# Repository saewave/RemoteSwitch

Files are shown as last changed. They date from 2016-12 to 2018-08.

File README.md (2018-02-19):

# RemoteSwitch

Проект RemoteSwitch создан для тех, кто самостоятельно занимается разработкой систем домайшеней автоматизации но сталкивается с рядом проблем, таких как:
- передача данных по радио каналу;
- разработка схемотехники для исполнительных устройств;
- разработка модуля для управления устройствами (хаб);
- организации беспроводной сети.

Проект домашней автоматизации на базе SaeWave RemoteSwitch решает полностью или частично все вышеперечисленные проблемы. На данный момент характеристики системы такие:
- Частота радиоканала 433 МГц.
- Скорость передачи данных от 1200 кБит
- Дальность устойчивого приема на открытом пространстве - 300м (дальность зависит от помех, наличия препятствий и используемых антенн).
- Подтверждение приема - да (при соответствующих настройках)
- Повторение отправки пакета - да (при соответствующих настройках)
- Подпись пакета - CRC
- Возможность обновления прошивки по воздуху

Проект является полностью открытыми, все исходные коды, схемы и списки деталей являются общедоступными для использования и повторения.

Проект распространяется под лицензией GPLv3 - это означает то, что если ваш проект будет полностью или частично построен на базе SaeWave RemoteSwitch он должен быть открытым.

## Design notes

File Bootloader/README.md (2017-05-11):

Шаблон для бутлоадера под STM32F0xx серию. Бутлоадер позволяет выполнить произвольный код, а потом перейти на произвольный адрес дя выполнения основного кода программы. Для этого программа должна быть загружена во флеш память и адрес, на который будет передано управление должен содержать начало исполняемого кода.
Для корректной работы прерываний основной программы таблица векторов должна быть перенесена в начало оперативной памяти и смещана относительно размера бутлоадера. Это особенности архитектуры STM32F0 серии. В других сериях мы можем переопределить саму таблицу векторов без ее полного переноса.

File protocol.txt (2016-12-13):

HUB Package structure (request)
	header: 1
	hubID:  5 (the length maybe configured in header) (should be same as device address for nRF24L01)
	command:1 (the length maybe configured in header)
	data:   depends on command

header bits (MSB-LSB):
	reserved
	reserved
	reserved
	reserved
	reserved
	number of package: 0=first package, 1=second (in this case data should be concatenated to data received early)
	hubID length: 0=5 byte, 1=8 byte
	command length: 0=1 byte, 2=more than 1 byte

Device package structure (request/response)
	header: 1
	deviceID: 5 (should be same as device address for nRF24L01)

Формирование адреса устройства:
Адрес устройства состоит из 5 байт.
При включении устройства, не важно, хаб это или исполнительное устройство адрес формируется их последних 5 байт серийного номера МК.
Если получить адрес МК не представляется возможным, то адрес устройства = 00-00-00-00-00 (или тот, который задан в файле nRF24L01P)
	
Поиск нового устройства хабом:
0) Подключение устройства к питанию, инициализация устройства. Включение приема или передачи данных.
1) На устройстве должен быть включен режим обнаружения. При этом устройство переходит в режим приема с адресом 00-00-00-00-00
2) Хаб отправляет команду обнаружения на адрес 00-00-00-00-00. Команда содержить автоматически (или тот, который задан в файле nRF24L01P) сгенерированный уникальный адрес для конкретного устройста.
3) Устройство принимает команду и распознает её. 
4) Формирует и отправляет ответ, данные ответа содержат команду подтверждения обнаружения, реальный (присвоенный) адрес устройства и тип устройства. Так же может содержать доп. информацию в зависимости от типа.
   4.1) Устройство переходит в штатный режим работы. При этом, если требуется режим приема, то устанавливается реальный адрес устройства полученный от хаба.
   4.2) Устройство так же запоминает адрес хаба у себя в памяти.
5) Хаб получает ответ от устройства, производит поиск устройств среди ранее сохраненных в памяти и обновляет данные либо добавляет новое устройство.

Примечание:
	Для работы в штатном режиме каждая полученная команда сравнивается с адресом хаба к которому была произведена привязка и только потом передается на исполнение.
	Это необходимо для того, чтоб не было ложных срабатываний от других хабов. Устройство можно подвязать к нескольким хабам (в этом случае алгоритм привязки меняется)
	
Передача данных от хаба к устройству:
0) Хаб, получив команду на передачу данных на устройство производит поиск устройства в таблице привязанных устройств и, если таковое устройство было ранее добавлено, вызывает функцию формирования пакета.
1) Пакет для передачи формируется из заголовка, данных и подписи.
2) Сформированный пакет передается на передатчик для отправки устройству. При этом сам процесс передачи контроллируется передатчиком.
3) Хаб отслеживает состояние отправки данных по внешнему прерыванию от передатчика, а так же по состоянию статусного регистра передатчика.
4) В зависимости от того, были ли переданны данные или нет, хаб возвращает статусную информацию в USART.

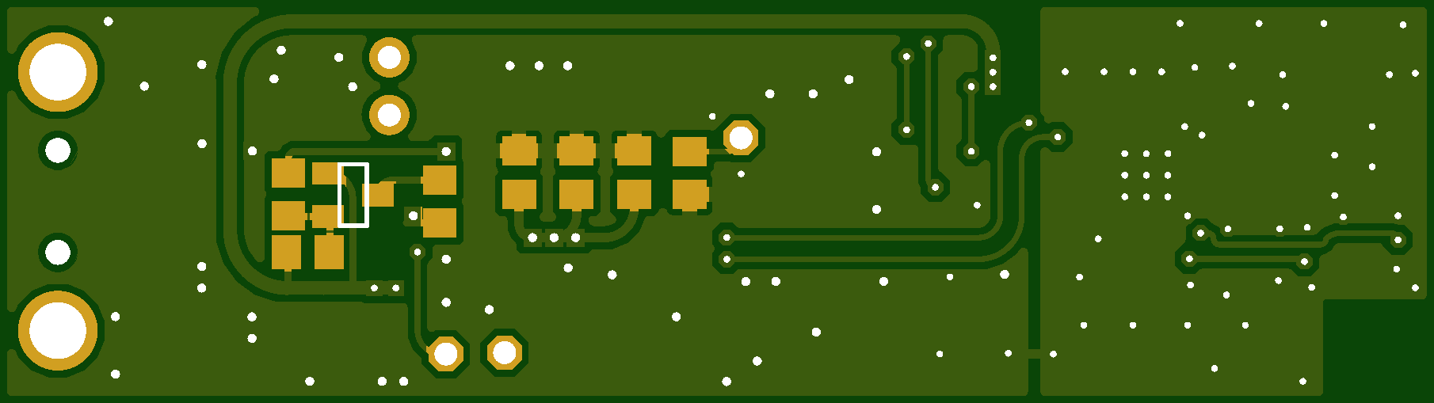
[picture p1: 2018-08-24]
SchematicAndBoards/Hub USB 2.0/Hub USB 2.0 Bottom.png

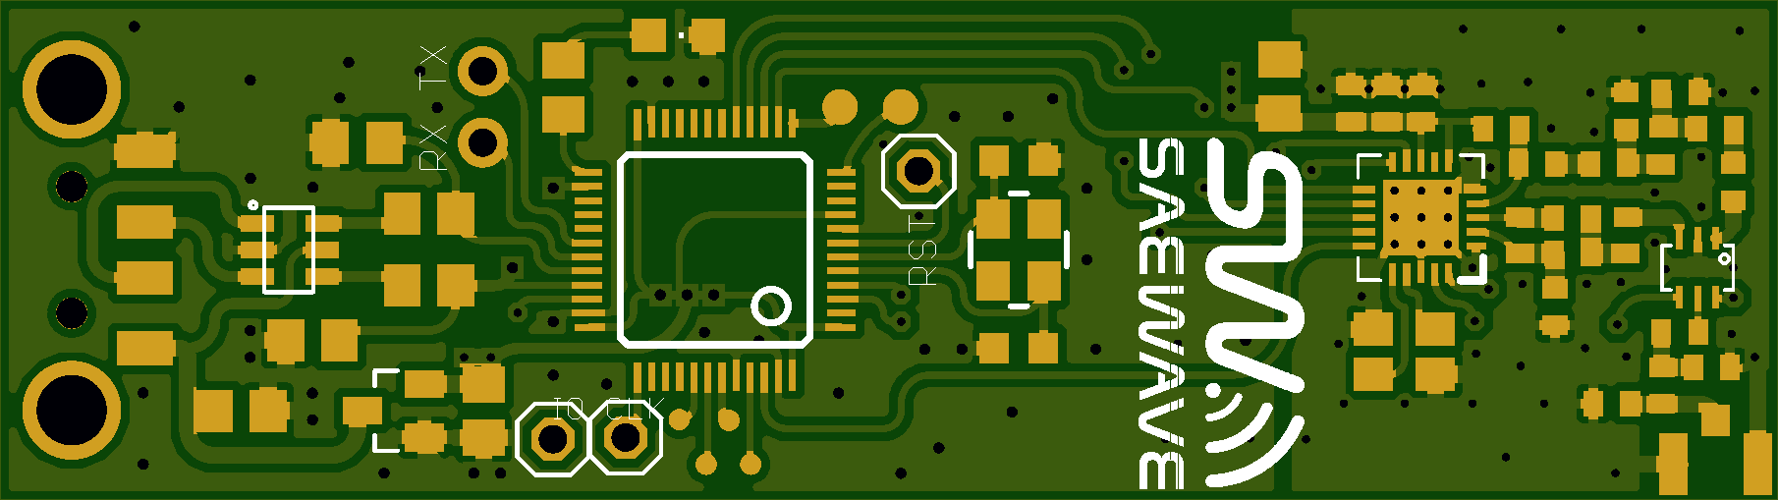
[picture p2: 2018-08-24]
SchematicAndBoards/Hub USB 2.0/Hub USB 2.0 Top.png

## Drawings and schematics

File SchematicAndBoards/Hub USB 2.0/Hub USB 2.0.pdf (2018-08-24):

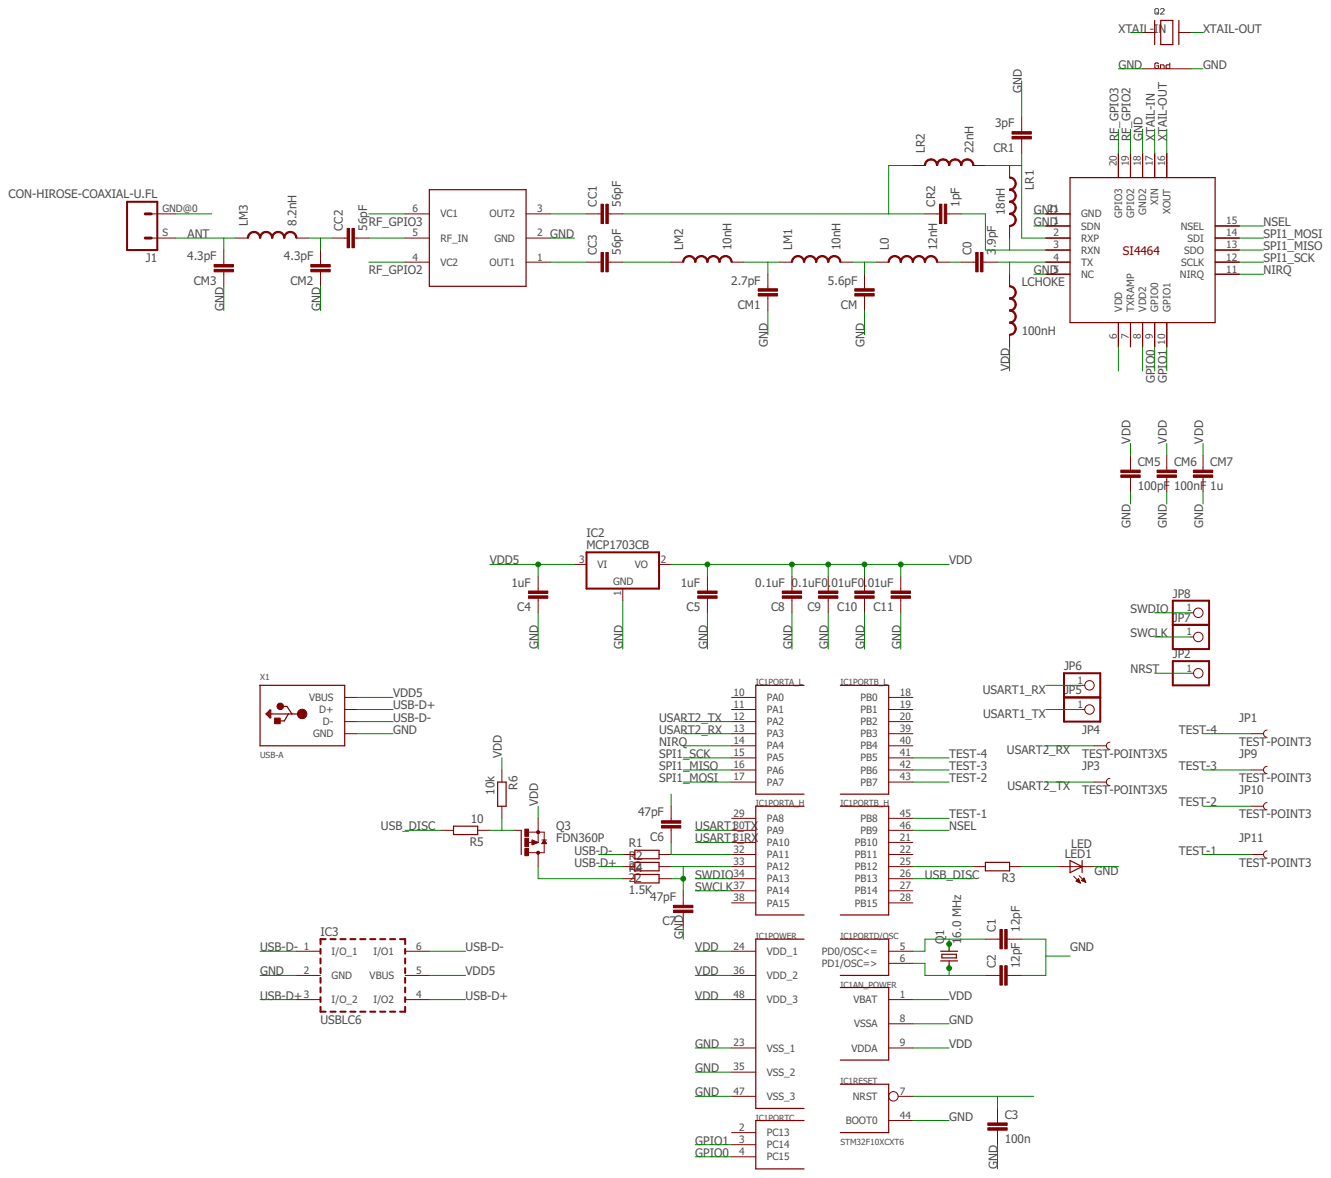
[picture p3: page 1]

CON-HIROSE-COAXIAL-U.FL

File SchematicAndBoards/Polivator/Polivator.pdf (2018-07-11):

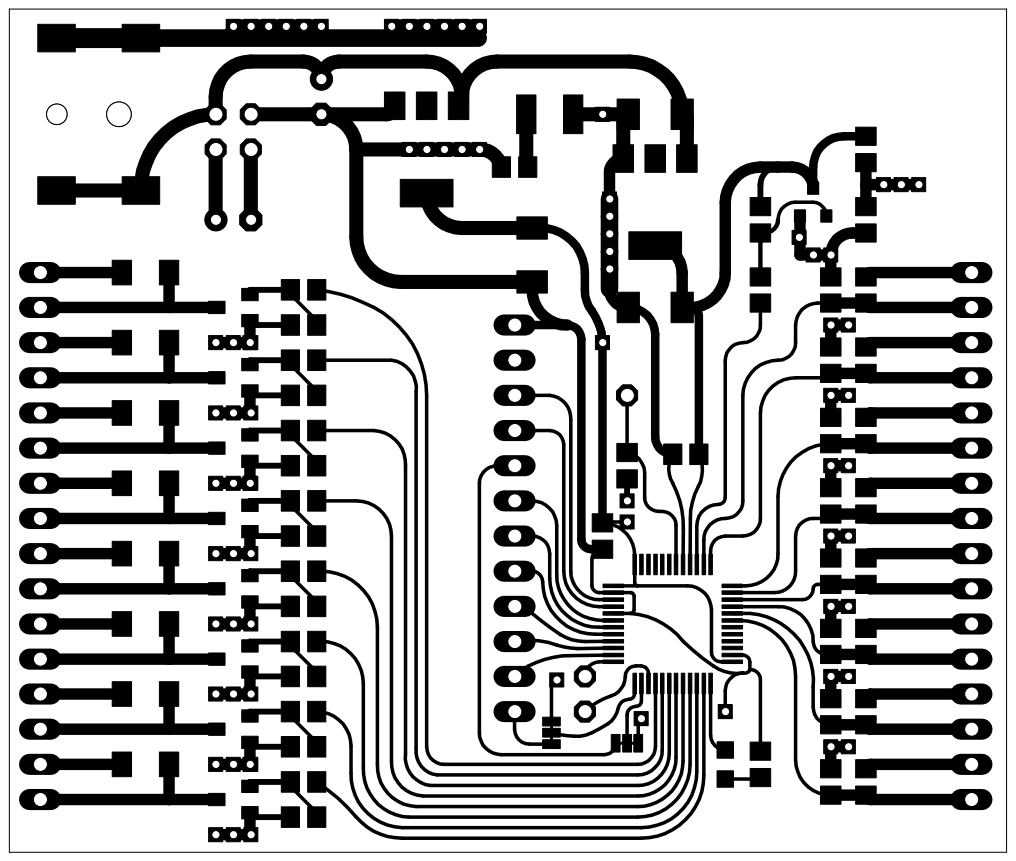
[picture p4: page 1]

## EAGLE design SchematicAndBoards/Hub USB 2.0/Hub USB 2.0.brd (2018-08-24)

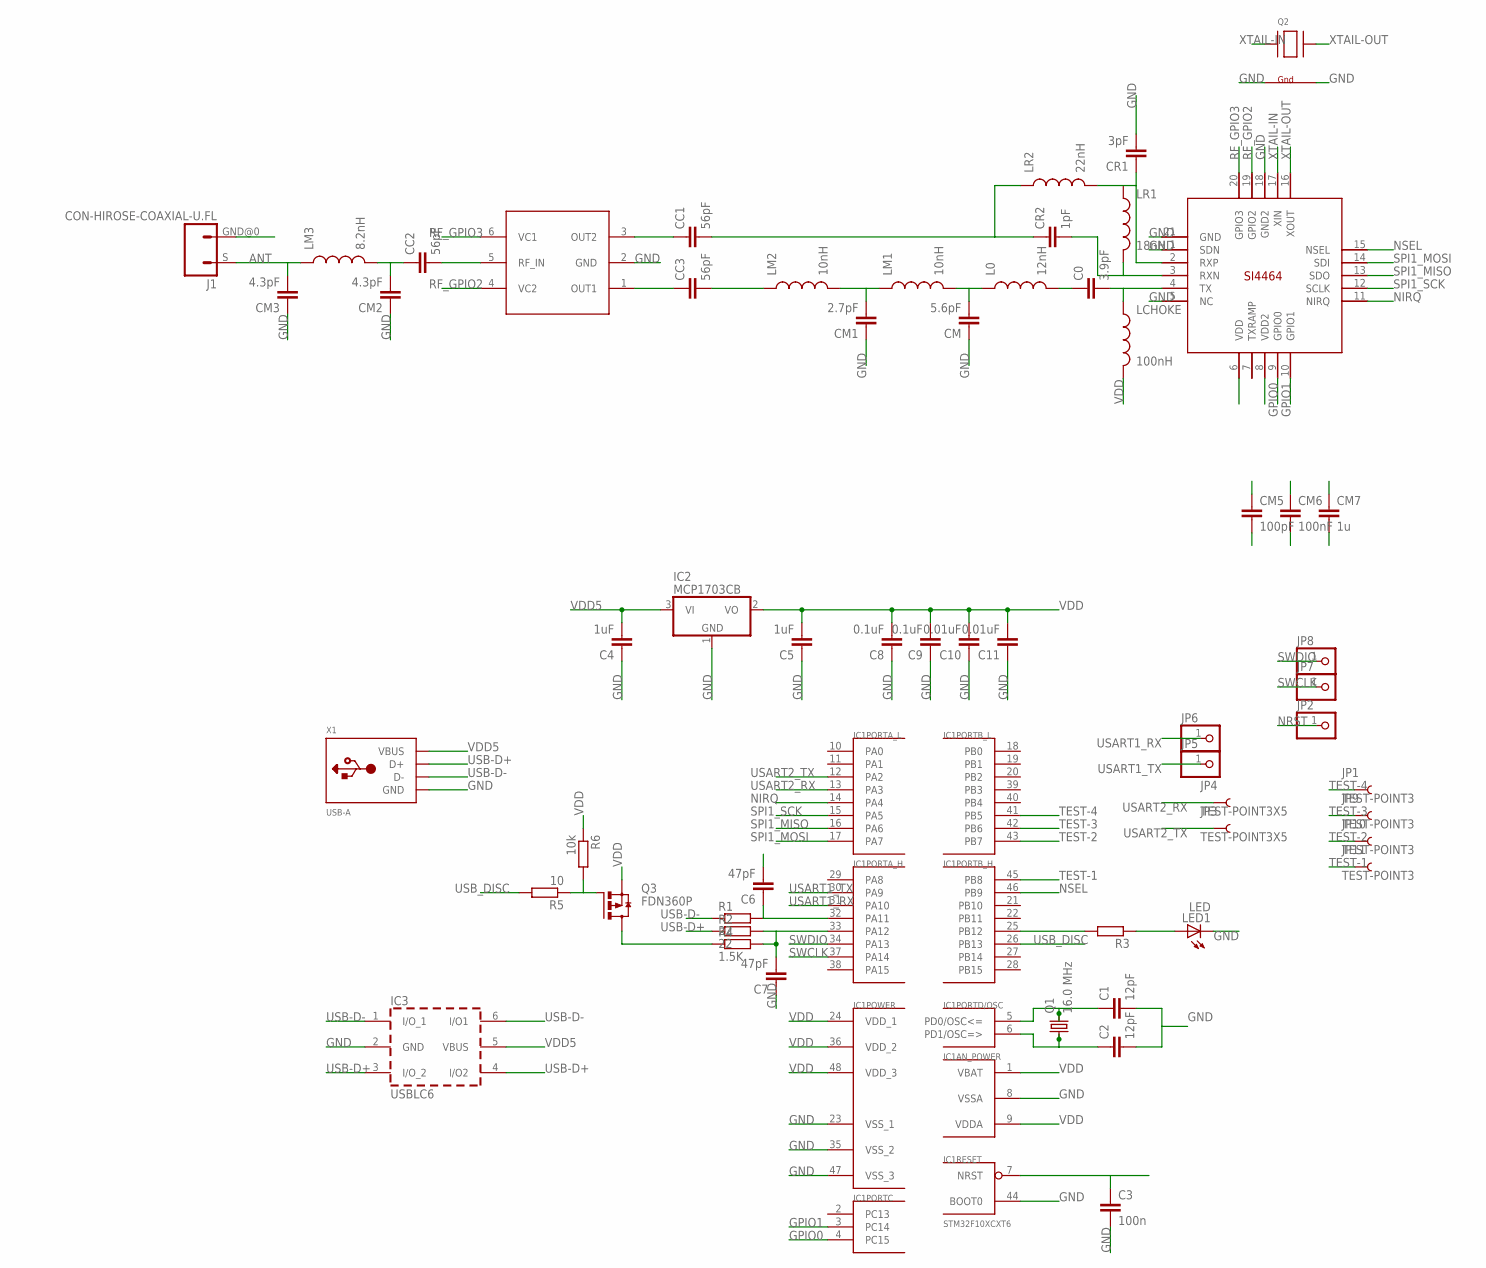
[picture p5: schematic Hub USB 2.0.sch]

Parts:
C0: 3.9pF; C0402
C1, C2: 12pF; C0603K
C3: 100n; C0805
C4, C5: 1uF; C0805
C6, C7: 47pF; C0805
C8, C9: 0.1uF; C0805
C10, C11: 0.01uF; C0805
CC1, CC2, CC3: 56pF; C0402
CM: 5.6pF; C0402
CM1: 2.7pF; C0402
CM2, CM3: 4.3pF; C0402
CM5: 100pF; C0402
CM6: 100nF; C0402
CM7: 1u; C0402
CR1: 3pF; C0402
CR2: 1pF; C0402
IC1: STM32F10XCXT6; TQFP48
IC2: MCP1703CB; SOT23
IC3: USBLC6; SOT-23-6L
J1: CON-HIROSE-COAXIAL-U.FL; CON-U.FL
JP1, JP9, JP10, JP11: TEST-POINT3; PAD.03X.03
JP2, JP7, JP8: PINHD-1X1; 1X01
JP3, JP4: TEST-POINT3X5; PAD.03X.05
JP5, JP6: PINHD-1X1CB; 1X01-CLEANBIG
L0: 12nH; C0402
LCHOKE: 100nH; C0402
LED1: LED; CHIPLED_0805
LM1, LM2: 10nH; C0402
LM3: 8.2nH; C0402
LR1: 18nH; C0402
LR2: 22nH; C0402
Q1: 16.0 MHz; CRYSTAL-SMD-3.2X2.5
Q2: XTAL-4-3225; NX3225
Q3: FDN360P; SUPER-SOT3
R1, R2: 22; R0805
R3: R-EU_R0805; R0805
R4: 1.5K; R0805
R5: 10; R0805
R6: 10k; R0805
U$1: SI4464; QFN20+GNDPAD
U$2: UPG2179TB; SUPER_MINIMOLD
X1: USB-A; MOLEX_480371000

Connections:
ANT: CM3.2, J1.S (1), LM3.1
GND: C1.2, C2.2, C3.2, C4.1, C5.1, C6.2, C7.1, C8.1, C9.1, C10.1, C11.1, CM.1, CM1.1, CM2.1, CM3.1, CM5.2, CM6.2, CM7.2, CR1.2, IC1.8 (VSSA), IC1.23 (VSS_1), IC1.35 (VSS_2), IC1.44 (BOOT0), IC1.47 (VSS_3), IC2.1 (GND), IC3.2 (GND), J1.GND@0 (2), LED1.C, Q2.2 (G2), Q2.4 (G1), U$1.1 (SDN), U$1.5 (NC), U$1.18 (GND2), U$1.21 (GND), U$2.2 (GND), X1.4 (GND)
GPIO0: IC1.4 (PC15), U$1.9 (GPIO0)
GPIO1: IC1.3 (PC14), U$1.10 (GPIO1)
unnamed: C1.1, IC1.5 (PD0/OSC<=), Q1.3 (2)
unnamed: C2.1, IC1.6 (PD1/OSC=>), Q1.1
unnamed: C0.2, LCHOKE.1, U$1.4 (TX)
unnamed: LED1.A, R3.1
unnamed: C0.1, L0.2
unnamed: C7.2, IC1.33 (PA12), R2.2, R4.2
unnamed: CM.2, L0.1, LM1.2
unnamed: CM1.2, LM1.1, LM2.2
unnamed: CC2.1, CM2.2, LM3.2
unnamed: C6.1, IC1.32 (PA11), R1.2
unnamed: CC3.1, U$2.1 (OUT1)
unnamed: CR2.2, LR1.2, U$1.3 (RXN)
unnamed: CC1.1, U$2.3 (OUT2)
unnamed: CR1.1, LR1.1, LR2.2, U$1.2 (RXP)
unnamed: IC1.25 (PB12), R3.2
unnamed: CC2.2, U$2.5 (RF_IN)
unnamed: CC3.2, LM2.1
unnamed: CC1.2, CR2.1, LR2.1
unnamed: Q3.3 (D), R4.1
unnamed: Q3.1 (G), R5.1, R6.2
NIRQ: IC1.14 (PA4), U$1.11 (NIRQ)
NRST: C3.1, IC1.7 (NRST), JP2.1
NSEL: IC1.46 (PB9), U$1.15 (NSEL)
RF_GPIO2: U$1.19 (GPIO2), U$2.4 (VC2)
RF_GPIO3: U$1.20 (GPIO3), U$2.6 (VC1)
SPI1_MISO: IC1.16 (PA6), U$1.13 (SDO)
SPI1_MOSI: IC1.17 (PA7), U$1.14 (SDI)
SPI1_SCK: IC1.15 (PA5), U$1.12 (SCLK)
SWCLK: IC1.37 (PA14), JP7.1
SWDIO: IC1.34 (PA13), JP8.1
TEST-1: IC1.45 (PB8), JP11.P$1
TEST-2: IC1.43 (PB7), JP10.P$1
TEST-3: IC1.42 (PB6), JP9.P$1
TEST-4: IC1.41 (PB5), JP1.P$1
USART1_RX: IC1.31 (PA10), JP6.1
USART1_TX: IC1.30 (PA9), JP5.1
USART2_RX: IC1.13 (PA3), JP4.P$1
USART2_TX: IC1.12 (PA2), JP3.P$1
USB-D+: IC3.3 (I/O_2), IC3.4 (I/O2), R2.1, X1.3 (D+)
USB-D-: IC3.1 (I/O_1), IC3.6 (I/O1), R1.1, X1.2 (D-)
USB_DISC: IC1.26 (PB13), R5.2
VDD: C5.2, C8.2, C9.2, C10.2, C11.2, CM5.1, CM6.1, CM7.1, IC1.1 (VBAT), IC1.9 (VDDA), IC1.24 (VDD_1), IC1.36 (VDD_2), IC1.48 (VDD_3), IC2.2 (VO), LCHOKE.2, Q3.2 (S), R6.1, U$1.6 (VDD), U$1.8 (VDD2)
VDD5: C4.2, IC2.3 (VI), IC3.5 (VBUS), X1.1 (VBUS)
XTAIL-IN: Q2.1 (X1), U$1.17 (XIN)
XTAIL-OUT: Q2.3 (X2), U$1.16 (XOUT)

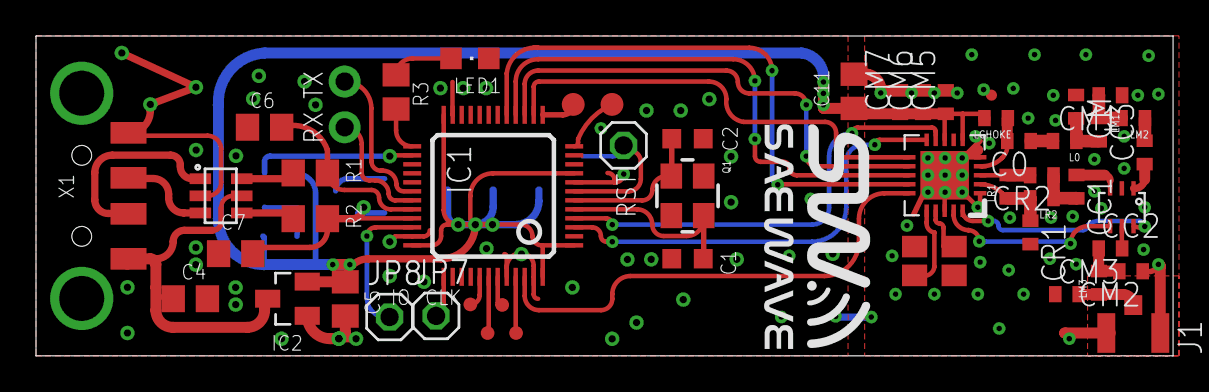
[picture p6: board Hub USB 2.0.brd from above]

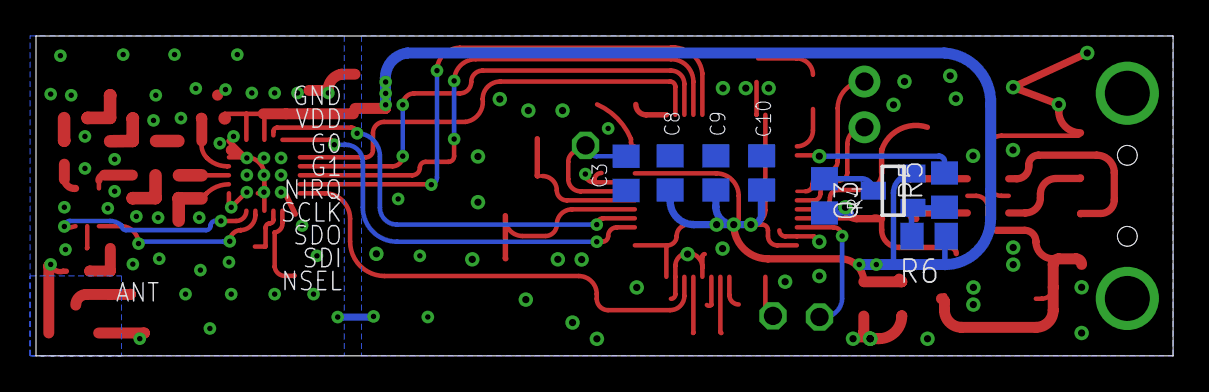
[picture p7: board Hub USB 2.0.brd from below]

Board: 2 copper layers, 63.2 x 17.8 mm, 59 parts (8 on the bottom side), 49 nets.

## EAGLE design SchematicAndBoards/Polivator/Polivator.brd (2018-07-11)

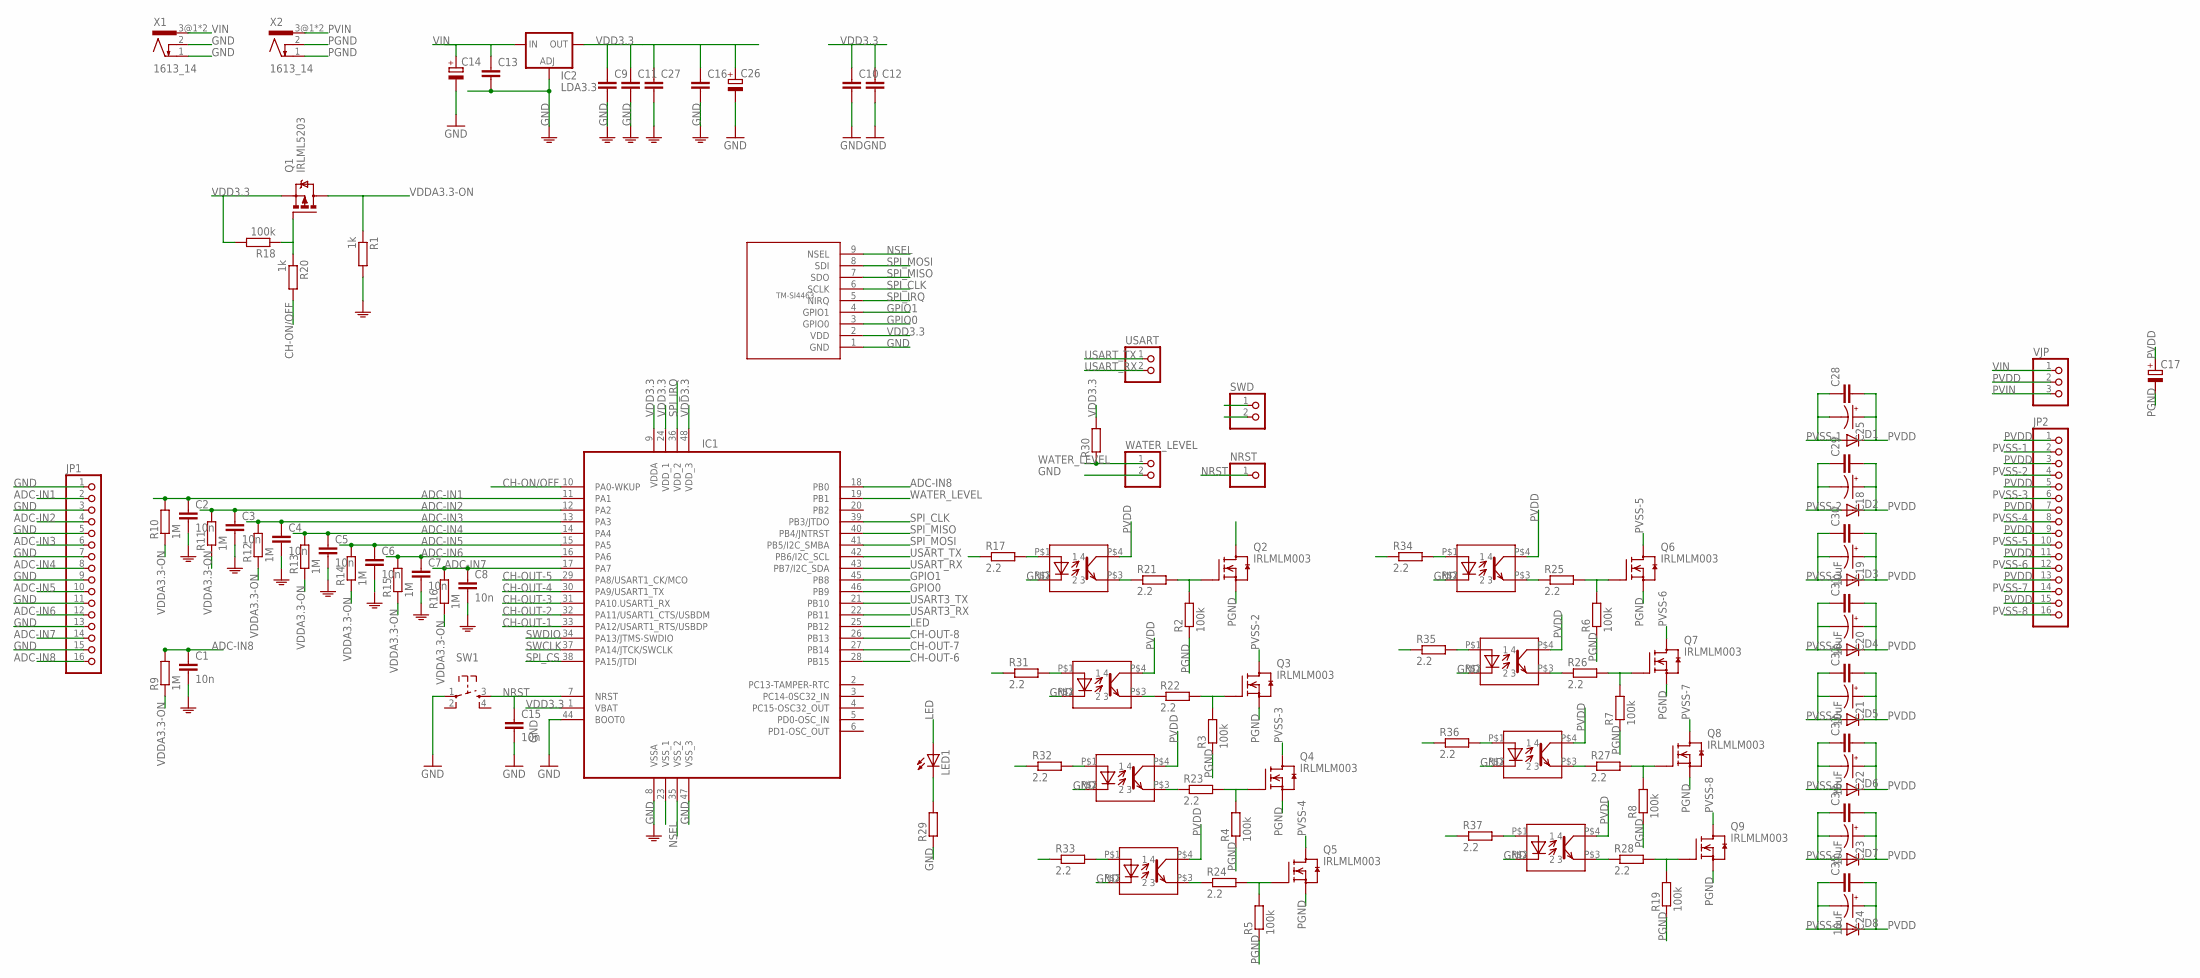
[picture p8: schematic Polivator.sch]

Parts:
C1, C2, C3, C4, C5, C6, C7, C8, C15: 10n; C0805
C9, C10: C-EUC3216; C3216
C11, C12, C16, C27, C28, C29, C30, C31, C32, C33, C34, C35: C-EUC0805; C0805
C13: C-EUC1808; C1808
C14, C26: CPOL-EUE2.5-5; E2,5-5
C17: CPOL-EUE2.5-6; E2,5-6
C18, C25: CAP_POL1206; EIA3216
C19, C20, C21, C22, C23, C24: 10uF; EIA3216
D1, D2, D3, D4, D5, D6, D7, D8: DIODE-SOD80C; SOD80C
IC1: IC_UC_STM32; LQFP48
IC2: LDA3.3; SOT223
JP1, JP2: PINHD-1X16; 1X16
LED1: LEDCHIPLED_0805; CHIPLED_0805
NRST: PINHD-1X1; 1X01
Q1: IRLML5203; MICRO3
Q2, Q3, Q4, Q5, Q6, Q7, Q8, Q9: IRLMLM003; SOT23
R1, R20: 1k; R0805
R2, R3, R4, R5, R6, R7, R8, R18, R19: 100k; R0805
R9, R10, R11, R12, R13, R14, R15, R16: 1M; R0805
R17, R21, R22, R23, R24, R25, R26, R27, R28, R31, R32, R33, R34, R35, R36, R37: 2.2; R0805
R29, R30: R-EU_R0805; R0805
SW1: SW_TACT_4P; SW_TACT_SMALL
SWD: PINHD-1X2; 1X02
U$8: TM-SI4463; TM-SI4463-SMD
U$10, U$11, U$13, U$16, U$18, U$20, U$23, U$24: PC817-SMD
USART: PINHD-1X2; 1X02
VJP: PINHD-1X3; 1X03
WATER_LEVEL: PINHD-1X2; 1X02
X1, X2: 1613_14

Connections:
ADC-IN1: C2.1, IC1.11 (PA1), JP1.2, R10.2
ADC-IN2: C3.1, IC1.12 (PA2), JP1.4, R11.2
ADC-IN3: C4.1, IC1.13 (PA3), JP1.6, R12.2
ADC-IN4: C5.1, IC1.14 (PA4), JP1.8, R13.2
ADC-IN5: C6.1, IC1.15 (PA5), JP1.10, R14.2
ADC-IN6: C7.1, IC1.16 (PA6), JP1.12, R15.2
ADC-IN7: C8.1, IC1.17 (PA7), JP1.14, R16.2
ADC-IN8: C1.1, IC1.18 (PB0), JP1.16, R9.2
CH-ON/OFF: IC1.10 (PA0-WKUP), R20.2
CH-OUT-1: IC1.33 (PA12/USART1_RTS/USBDP), R17.1
CH-OUT-2: IC1.32 (PA11/USART1_CTS/USBDM), R31.1
CH-OUT-3: IC1.31 (PA10.USART1_RX), R32.1
CH-OUT-4: IC1.30 (PA9/USART1_TX), R33.1
CH-OUT-5: IC1.29 (PA8/USART1_CK/MCO), R34.1
CH-OUT-6: IC1.28 (PB15), R35.1
CH-OUT-7: IC1.27 (PB14), R36.1
CH-OUT-8: IC1.26 (PB13), R37.1
GND: C1.2, C2.2, C3.2, C4.2, C5.2, C6.2, C7.2, C8.2, C9.2, C10.2, C11.2, C12.2, C13.2, C14.-, C15.2, C16.2, C26.-, C27.2, IC1.8 (VSSA), IC1.23 (VSS_1), IC1.44 (BOOT0), IC1.47 (VSS_3), IC2.1 (ADJ), JP1.1, JP1.3, JP1.5, JP1.7, JP1.9, JP1.11, JP1.13, JP1.15, R1.2, R29.1, SW1.1, U$8.1 (GND), U$10.P$2 (2), U$11.P$2 (2), U$13.P$2 (2), U$16.P$2 (2), U$18.P$2 (2), U$20.P$2 (2), U$23.P$2 (2), U$24.P$2 (2), WATER_LEVEL.2, X1.1, X1.2
GPIO0: IC1.46 (PB9), U$8.3 (GPIO0)
GPIO1: IC1.45 (PB8), U$8.4 (GPIO1)
LED: IC1.25 (PB12), LED1.A
unnamed: LED1.C, R29.2
unnamed: Q2.1 (G), R2.2, R21.2
unnamed: Q3.1 (G), R3.2, R22.2
unnamed: Q1.1 (G), R18.1, R20.1
unnamed: Q4.1 (G), R4.2, R23.2
unnamed: R21.1, U$10.P$3 (3)
unnamed: R22.1, U$11.P$3 (3)
unnamed: Q5.1 (G), R5.2, R24.2
unnamed: Q6.1 (G), R6.2, R25.2
unnamed: Q7.1 (G), R7.2, R26.2
unnamed: Q8.1 (G), R8.2, R27.2
unnamed: Q9.1 (G), R19.2, R28.2
unnamed: R23.1, U$13.P$3 (3)
unnamed: R24.1, U$16.P$3 (3)
unnamed: R25.1, U$18.P$3 (3)
unnamed: R26.1, U$20.P$3 (3)
unnamed: R27.1, U$23.P$3 (3)
unnamed: R28.1, U$24.P$3 (3)
unnamed: R17.2, U$10.P$1 (1)
unnamed: R31.2, U$11.P$1 (1)
unnamed: R32.2, U$13.P$1 (1)
unnamed: R33.2, U$16.P$1 (1)
unnamed: R37.2, U$24.P$1 (1)
unnamed: R36.2, U$23.P$1 (1)
unnamed: R35.2, U$20.P$1 (1)
unnamed: R34.2, U$18.P$1 (1)
NRST: C15.1, IC1.7 (NRST), NRST.1, SW1.3
NSEL: IC1.35 (VSS_2), U$8.9 (NSEL)
PGND: C17.-, Q2.2 (S), Q3.2 (S), Q4.2 (S), Q5.2 (S), Q6.2 (S), Q7.2 (S), Q8.2 (S), Q9.2 (S), R2.1, R3.1, R4.1, R5.1, R6.1, R7.1, R8.1, R19.1, X2.1, X2.2
PVDD: C17.+, C18.A (+), C19.A (+), C20.A (+), C21.A (+), C22.A (+), C23.A (+), C24.A (+), C25.A (+), C28.2, C29.2, C30.2, C31.2, C32.2, C33.2, C34.2, C35.2, D1.C, D2.C, D3.C, D4.C, D5.C, D6.C, D7.C, D8.C, JP2.1, JP2.3, JP2.5, JP2.7, JP2.9, JP2.11, JP2.13, JP2.15, U$10.P$4 (4), U$11.P$4 (4), U$13.P$4 (4), U$16.P$4 (4), U$18.P$4 (4), U$20.P$4 (4), U$23.P$4 (4), U$24.P$4 (4), VJP.2
PVIN: VJP.3, X2.3@1 (3), X2.3@2 (3)
PVSS-1: C25.C (-), C28.1, D1.A, JP2.2, Q2.3 (D)
PVSS-2: C18.C (-), C29.1, D2.A, JP2.4, Q3.3 (D)
PVSS-3: C19.C (-), C30.1, D3.A, JP2.6, Q4.3 (D)
PVSS-4: C20.C (-), C31.1, D4.A, JP2.8, Q5.3 (D)
PVSS-5: C21.C (-), C32.1, D5.A, JP2.10, Q6.3 (D)
PVSS-6: C22.C (-), C33.1, D6.A, JP2.12, Q7.3 (D)
PVSS-7: C23.C (-), C34.1, D7.A, JP2.14, Q8.3 (D)
PVSS-8: C24.C (-), C35.1, D8.A, JP2.16, Q9.3 (D)
SPI_CLK: IC1.39 (PB3/JTDO), U$8.6 (SCLK)
SPI_CS: IC1.38 (PA15/JTDI)
SPI_IRQ: IC1.36 (VDD_2), U$8.5 (NIRQ)
SPI_MISO: IC1.40 (PB4/JNTRST), U$8.7 (SDO)
SPI_MOSI: IC1.41 (PB5/I2C_SMBA), U$8.8 (SDI)
SWCLK: IC1.37 (PA14/JTCK/SWCLK), SWD.2
SWDIO: IC1.34 (PA13/JTMS-SWDIO), SWD.1
USART3_RX: IC1.22 (PB11)
USART3_TX: IC1.21 (PB10)
USART_RX: IC1.43 (PB7/I2C_SDA), USART.2
USART_TX: IC1.42 (PB6/I2C_SCL), USART.1
VDD3.3: C9.1, C10.1, C11.1, C12.1, C16.1, C26.+, C27.1, IC1.1 (VBAT), IC1.9 (VDDA), IC1.24 (VDD_1), IC1.48 (VDD_3), IC2.4 (OUT), Q1.2 (S), R18.2, R30.2, U$8.2 (VDD)
VDDA3.3-ON: Q1.3 (D), R1.1, R9.1, R10.1, R11.1, R12.1, R13.1, R14.1, R15.1, R16.1
VIN: C13.1, C14.+, IC2.3 (IN), VJP.1, X1.3@1 (3), X1.3@2 (3)
WATER_LEVEL: IC1.19 (PB1), R30.1, WATER_LEVEL.1

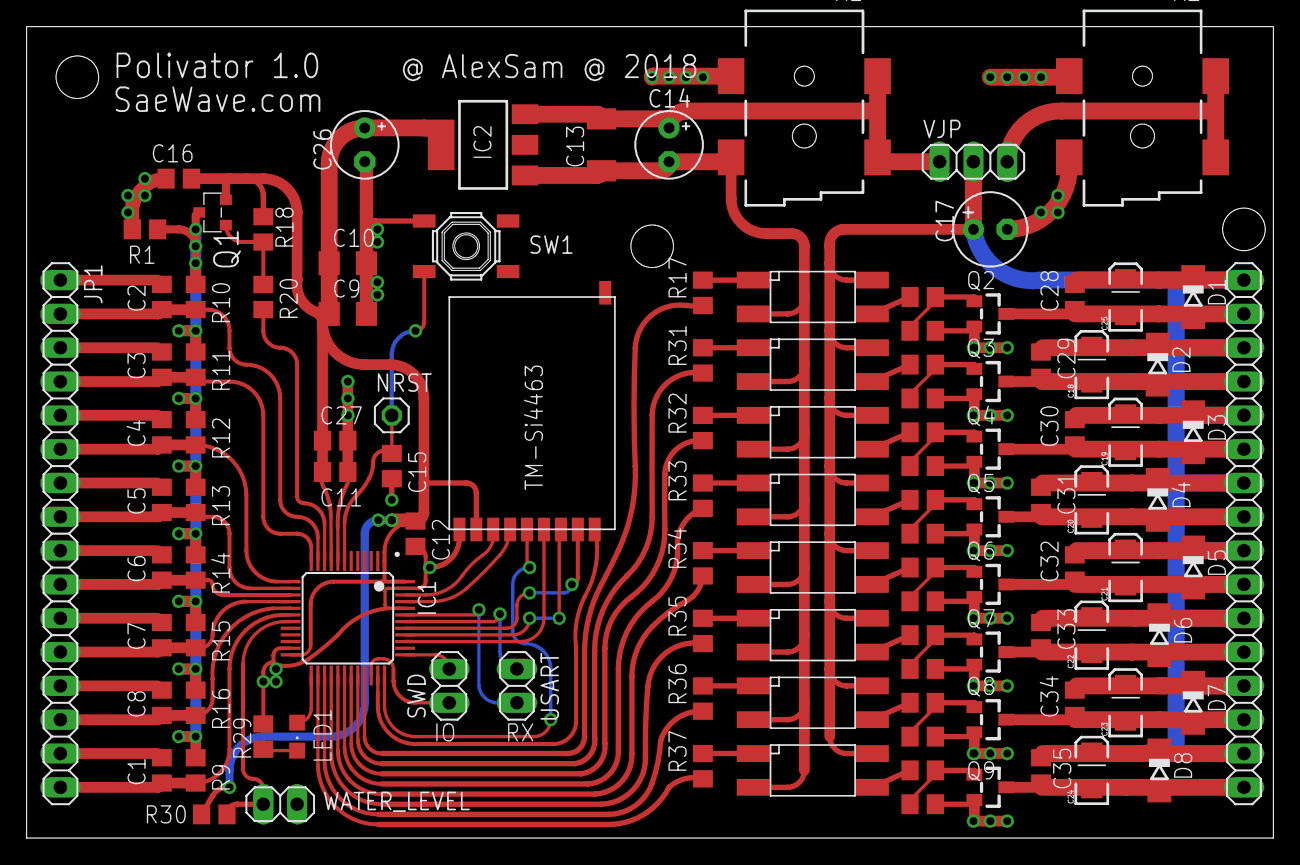
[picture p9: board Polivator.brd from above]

Board: 2 copper layers, 93.7 x 61.0 mm, 111 parts (0 on the bottom side), 72 nets.

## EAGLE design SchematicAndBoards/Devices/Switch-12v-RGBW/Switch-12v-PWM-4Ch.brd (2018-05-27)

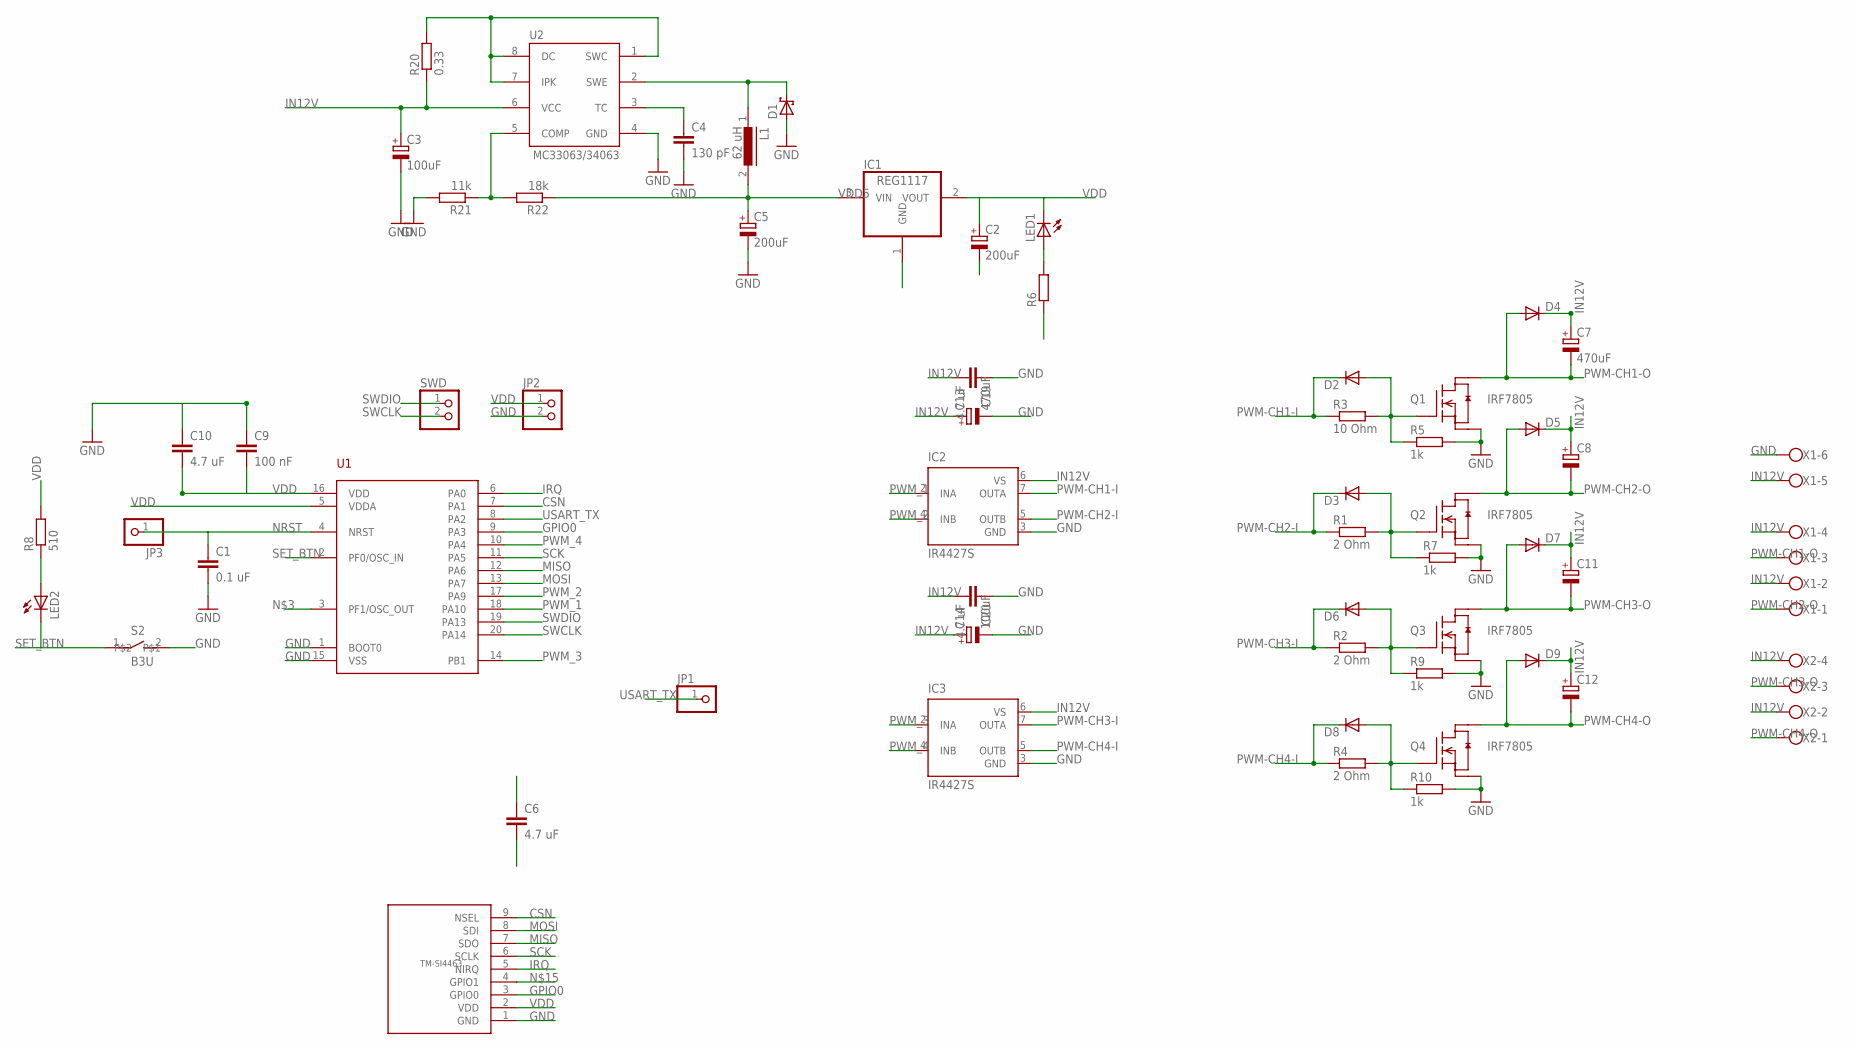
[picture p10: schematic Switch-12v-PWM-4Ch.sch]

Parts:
C1: 0.1 uF; C0805
C2, C5: 200uF; SMC_C
C3: 100uF; SMC_C
C4: 130 pF; C0805
C6, C10, C19, C20: 4.7 uF; C0805
C7: 470uF; E5-8,5
C8, C11, C12: CPOL-EUE5-8.5; E5-8,5
C9: 100 nF; C0805
C13: 470uF; 085CS_1AR
C14: 100uF; 085CS_1AR
D1: SCHOTTKY-DIODE; DIODE_SMB
D2, D3, D4, D5, D6, D7, D8, D9: DIODE-DO214BA; DO214BA
IC1: REG1117; SOT223
IC2, IC3: IR4427S; SO08
JP1, JP3: PINHD-1X1; 1X01
JP2: PINHD-1X2; 1X02
L1: 62 uH; DR73
LED1, LED2: LEDCHIPLED_0805; CHIPLED_0805
Q1, Q2, Q3, Q4: IRF7805; SO-8
R1, R2, R4: 2 Ohm; R0805
R3: 10 Ohm; R0805
R5, R7, R9, R10: 1k; R0805
R6: R-EU_R0805; R0805
R8: 510; R0805
R20: 0.33; R0805
R21: 11k; R0805
R22: 18k; R0805
S2: B3U; 1210
SWD: PINHD-1X2; 1X02
U1: STM32F030F4; TSSOP20
U2: MC33063/MC34063D; SO08
U$1: TM-SI4463; TM-SI4463-SMD
X1: W237-6
X2: W237-4

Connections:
CSN: U1.7 (PA1), U$1.9 (NSEL)
GND: C1.2, C2.-, C3.-, C4.2, C5.-, C6.2, C9.1, C10.1, C13.-, C14.-, C19.1, C20.1, D1.A (C), IC1.1 (GND), IC2.3 (GND), IC3.3 (GND), JP2.2, Q1.3 (S), Q2.3 (S), Q3.3 (S), Q4.3 (S), R5.2, R6.1, R7.2, R9.2, R10.2, R21.2, S2.2, U1.1 (BOOT0), U1.15 (VSS), U2.4 (GND), U$1.1 (GND), X1.6
GPIO0: U1.9 (PA3), U$1.3 (GPIO0)
IN12V: C3.+, C7.+, C8.+, C11.+, C12.+, C13.+, C14.+, C19.2, C20.2, D4.C, D5.C, D7.C, D9.C, IC2.6 (VS), IC3.6 (VS), R20.1, U2.6 (VCC), X1.2, X1.4, X1.5, X2.2, X2.4
IRQ: U1.6 (PA0), U$1.5 (NIRQ)
MISO: U1.12 (PA6), U$1.7 (SDO)
MOSI: U1.13 (PA7), U$1.8 (SDI)
unnamed: D2.A, Q1.4 (G), R3.2, R5.1
unnamed: D3.A, Q2.4 (G), R1.2, R7.1
unnamed: LED1.A, R6.2
unnamed: LED2.A, R8.1
unnamed: R21.1, R22.2, U2.5 (COMP)
unnamed: R20.2, U2.1 (SWC), U2.7 (IPK), U2.8 (DC)
unnamed: C4.1, U2.3 (TC)
unnamed: D1.C (A), L1.1, U2.2 (SWE)
unnamed: D6.A, Q3.4 (G), R2.2, R9.1
unnamed: D8.A, Q4.4 (G), R4.2, R10.1
NRST: C1.1, JP3.1, U1.4 (NRST)
PWM-CH1-I: D2.C, IC2.7 (OUTA), R3.1
PWM-CH1-O: C7.-, D4.A, Q1.8 (D), X1.3
PWM-CH2-I: D3.C, IC2.5 (OUTB), R1.1
PWM-CH2-O: C8.-, D5.A, Q2.8 (D), X1.1
PWM-CH3-I: D6.C, IC3.7 (OUTA), R2.1
PWM-CH3-O: C11.-, D7.A, Q3.8 (D), X2.3
PWM-CH4-I: D8.C, IC3.5 (OUTB), R4.1
PWM-CH4-O: C12.-, D9.A, Q4.8 (D), X2.1
PWM_1: IC2.2 (INA), U1.18 (PA10)
PWM_2: IC2.4 (INB), U1.17 (PA9)
PWM_3: IC3.2 (INA), U1.14 (PB1)
PWM_4: IC3.4 (INB), U1.10 (PA4)
SCK: U1.11 (PA5), U$1.6 (SCLK)
SET_BTN: LED2.C, S2.1, U1.2 (PF0/OSC_IN)
SWCLK: SWD.2, U1.20 (PA14)
SWDIO: SWD.1, U1.19 (PA13)
USART_TX: JP1.1, U1.8 (PA2)
VDD: C2.+, C6.1, C9.2, C10.2, IC1.2 (VOUT), JP2.1, LED1.C, R8.2, U1.5 (VDDA), U1.16 (VDD), U$1.2 (VDD)
VDD5: C5.+, IC1.3 (VIN), L1.2, R22.1

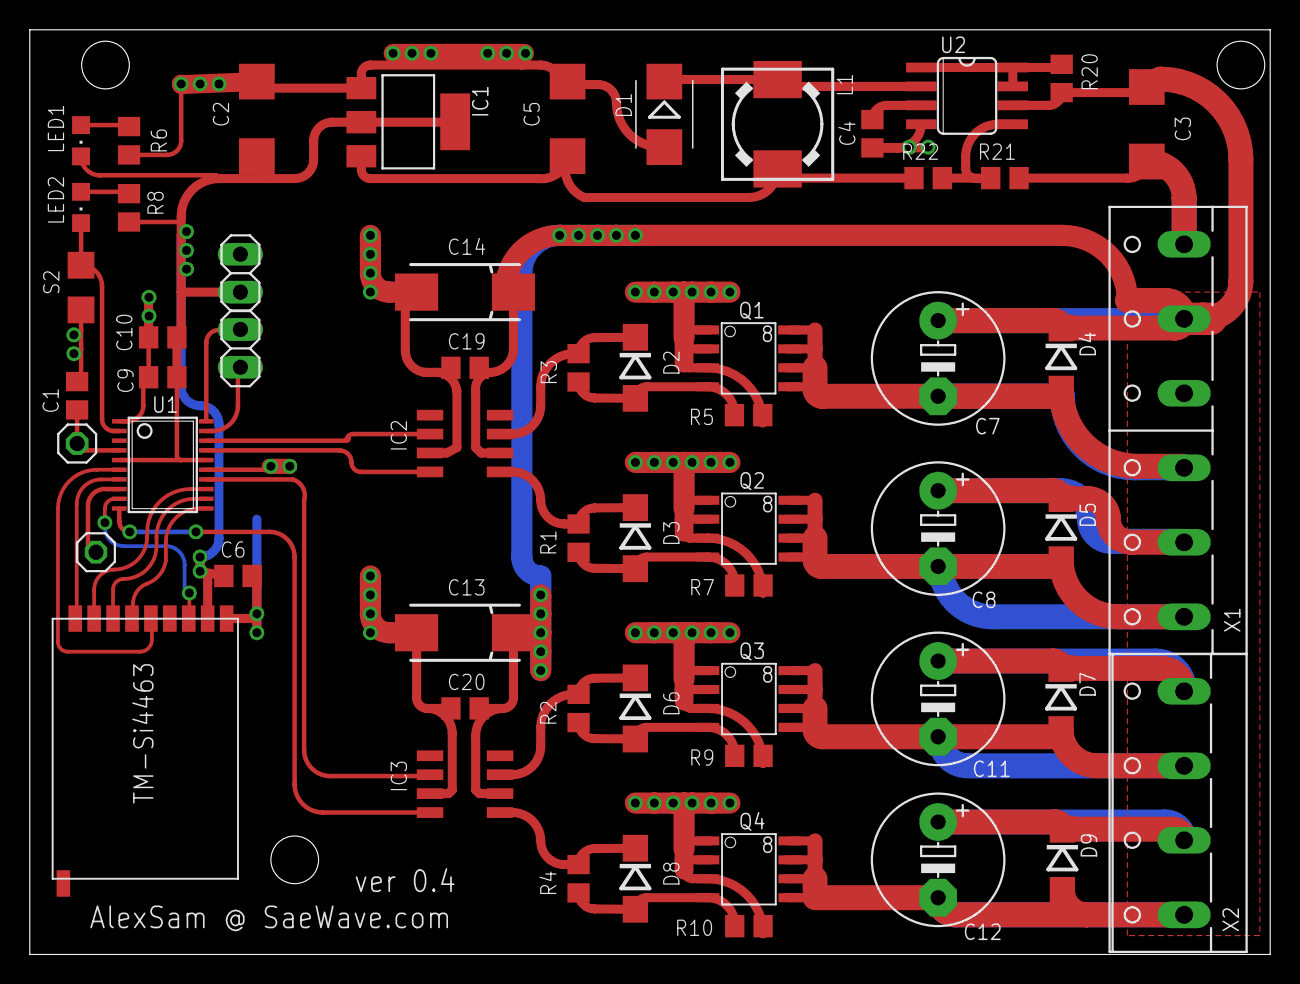
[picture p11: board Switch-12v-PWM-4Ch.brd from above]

Board: 2 copper layers, 83.2 x 62.1 mm, 58 parts (0 on the bottom side), 37 nets.

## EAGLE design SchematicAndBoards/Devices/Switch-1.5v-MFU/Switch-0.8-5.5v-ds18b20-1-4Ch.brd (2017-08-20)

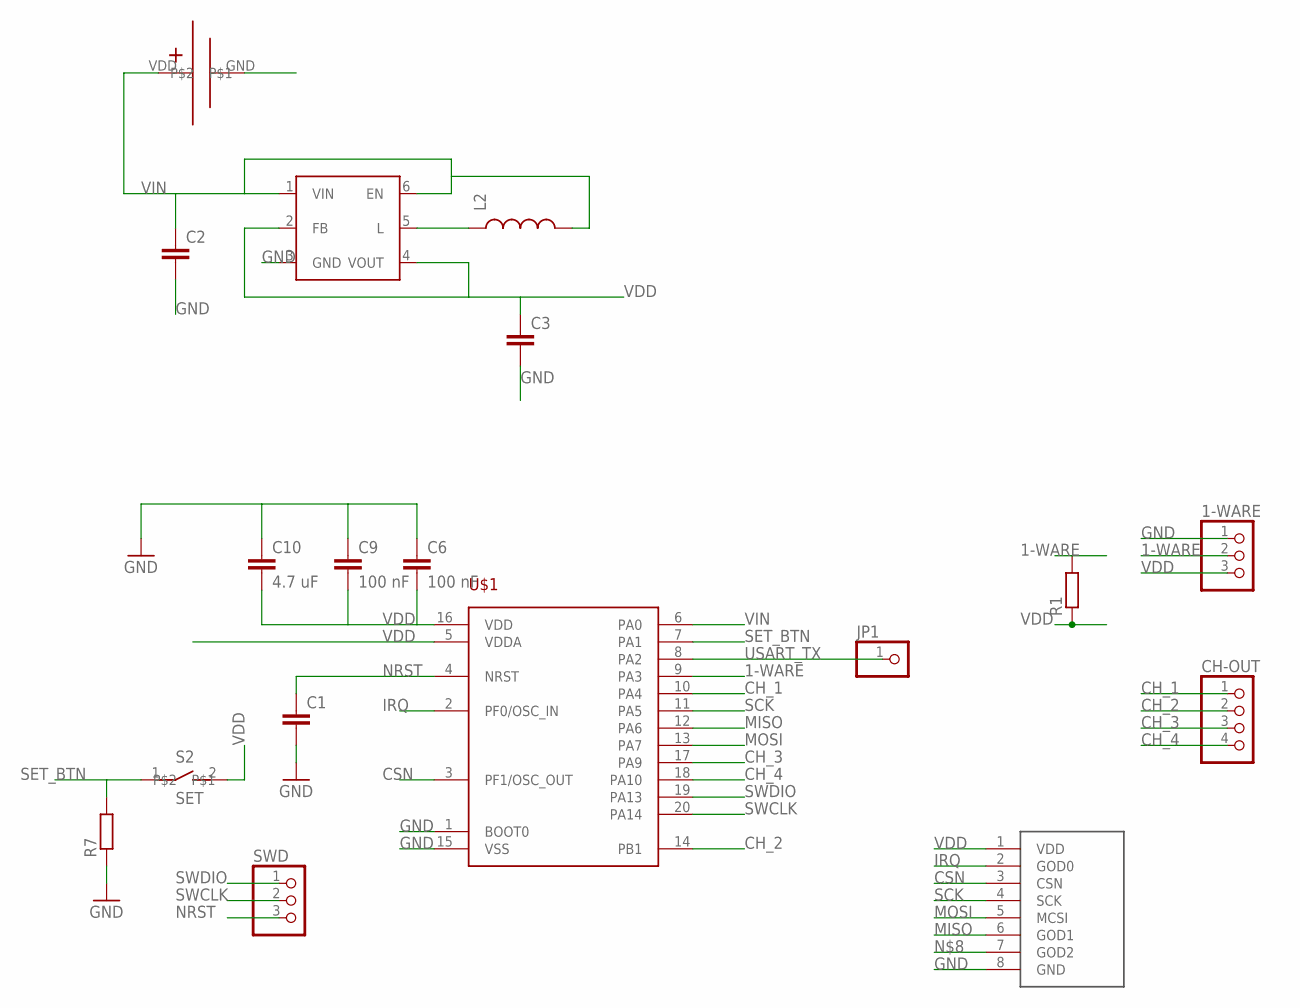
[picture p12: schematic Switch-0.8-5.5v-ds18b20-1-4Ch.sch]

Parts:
1-WARE: PINHD-1X3; 1X03
C1, C2, C3: C-EUC0805; C0805
C6, C9: 100 nF; C0805
C10: 4.7 uF; C0805
CH-OUT: PINHD-1X4_2.54; 1X04
JP1: PINHD-1X1CB; 1X01-CLEANBIG
L2: INDUCTOR1210; 1210
R1, R7: R-EU_R0805; R0805
S2: SET; 1210
SWD: PINHD-1X3CB; 1X03-CLEANBIG
U$1: STM32F030F4; TSSOP20
U$2: TPS61221; SC-70-6
U$3: AS07-M1101S
U$4: BAT-AA1-PCB-HOLDER

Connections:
1-WARE: 1-WARE.2, R1.2, U$1.9 (PA3)
CH_1: CH-OUT.1, U$1.10 (PA4)
CH_2: CH-OUT.2, U$1.14 (PB1)
CH_3: CH-OUT.3, U$1.17 (PA9)
CH_4: CH-OUT.4, U$1.18 (PA10)
CSN: U$1.3 (PF1/OSC_OUT), U$3.3 (CSN)
GND: 1-WARE.1, C1.2, C2.2, C3.2, C6.1, C9.1, C10.1, R7.1, U$1.1 (BOOT0), U$1.15 (VSS), U$2.3 (GND), U$3.8 (GND), U$4.GND
IRQ: U$1.2 (PF0/OSC_IN), U$3.2 (GOD0)
MISO: U$1.12 (PA6), U$3.6 (GOD1)
MOSI: U$1.13 (PA7), U$3.5 (MCSI)
unnamed: L2.1, U$2.5 (L)
NRST: C1.1, SWD.3, U$1.4 (NRST)
SCK: U$1.11 (PA5), U$3.4 (SCK)
SET_BTN: R7.2, S2.1, U$1.7 (PA1)
SWCLK: SWD.2, U$1.20 (PA14)
SWDIO: SWD.1, U$1.19 (PA13)
USART_TX: JP1.1, U$1.8 (PA2)
VDD: 1-WARE.3, C3.1, C6.2, C9.2, C10.2, R1.1, S2.2, U$1.5 (VDDA), U$1.16 (VDD), U$2.2 (FB), U$2.4 (VOUT), U$3.1 (VDD)
VIN: C2.1, L2.2, U$1.6 (PA0), U$2.1 (VIN), U$2.6 (EN), U$4.VDD

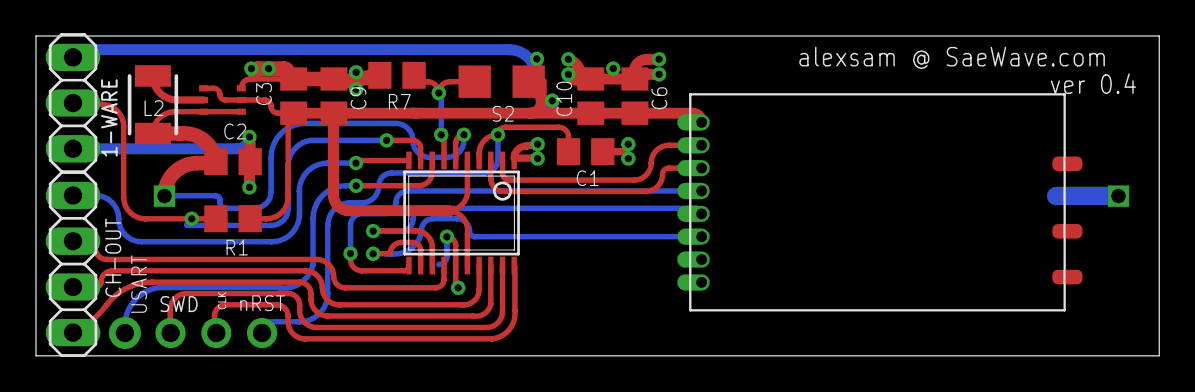
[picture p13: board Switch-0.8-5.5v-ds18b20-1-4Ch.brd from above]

Board: 2 copper layers, 62.4 x 17.8 mm, 18 parts (1 on the bottom side), 19 nets.

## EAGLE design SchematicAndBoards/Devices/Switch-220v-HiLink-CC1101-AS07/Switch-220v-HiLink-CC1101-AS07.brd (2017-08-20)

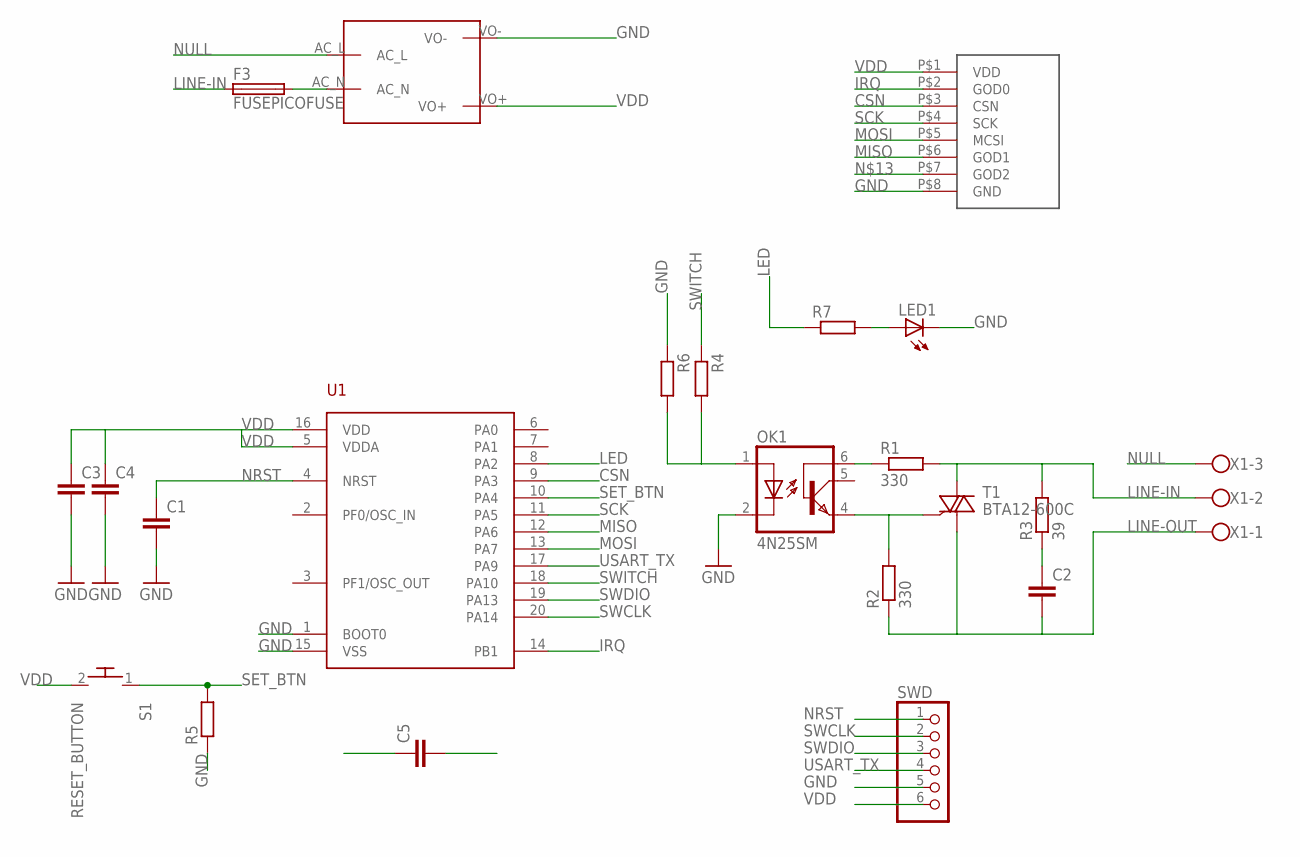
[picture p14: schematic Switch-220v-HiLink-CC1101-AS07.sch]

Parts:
C1, C3, C4, C5: C-EUC0805; C0805
C2: C-EU050-025X075; C050-025X075
F3: FUSEPICOFUSE; PICOFUSE
LED1: LEDCHIP-LED0805; CHIP-LED0805
OK1: 4N25SM; DIL6-SMD
R1: 330; 0207/2V
R2: 330; 0204/7
R3: 39; 0204/7
R4, R5, R6, R7: R-EU_R0805; R0805
S1: RESET_BUTTON; EVQ-PJU05K
SWD: PINHD-1X6B; 1X06-BIG
T1: BTA12-600C; TO220DS
U1: STM32F030F4; TSSOP20
U$2: MAINS_CONVERTERS; HLK-PM01
U$4: AS07-M1101SSMD; AS07-M1101S-SMD
X1: W237-103

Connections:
CSN: U1.9 (PA3), U$4.P$3 (CSN)
GND: C1.2, C3.2, C4.2, C5.1, LED1.C, OK1.2 (C), R5.1, R6.1, SWD.5, U1.1 (BOOT0), U1.15 (VSS), U$2.VO-, U$4.P$8 (GND)
IRQ: U1.14 (PB1), U$4.P$2 (GOD0)
LED: R7.1, U1.8 (PA2)
LINE-IN: F3.1, R1.2, R3.2, T1.A2, X1.2
LINE-OUT: C2.2, R2.1, T1.A1, X1.1
MISO: U1.12 (PA6), U$4.P$6 (GOD1)
MOSI: U1.13 (PA7), U$4.P$5 (MCSI)
unnamed: OK1.4 (EMI), R2.2, T1.G
unnamed: OK1.6 (BAS), R1.1
unnamed: LED1.A, R7.2
unnamed: F3.2, U$2.AC_N
unnamed: C2.1, R3.1
unnamed: OK1.1 (A), R4.2, R6.2
NRST: C1.1, SWD.1, U1.4 (NRST)
NULL: U$2.AC_L, X1.3
SCK: U1.11 (PA5), U$4.P$4 (SCK)
SET_BTN: R5.2, S1.1, U1.10 (PA4)
SWCLK: SWD.2, U1.20 (PA14)
SWDIO: SWD.3, U1.19 (PA13)
SWITCH: R4.1, U1.18 (PA10)
USART_TX: SWD.4, U1.17 (PA9)
VDD: C3.1, C4.1, C5.2, S1.2, SWD.6, U1.5 (VDDA), U1.16 (VDD), U$2.VO+, U$4.P$1 (VDD)

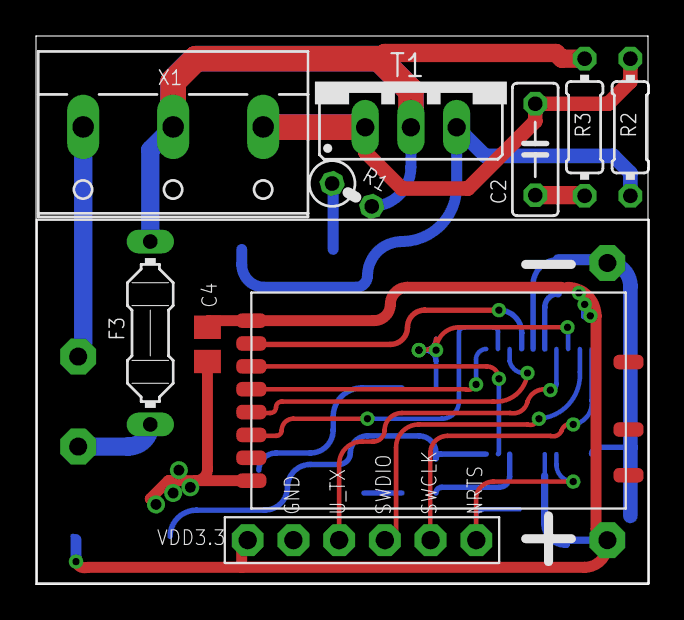
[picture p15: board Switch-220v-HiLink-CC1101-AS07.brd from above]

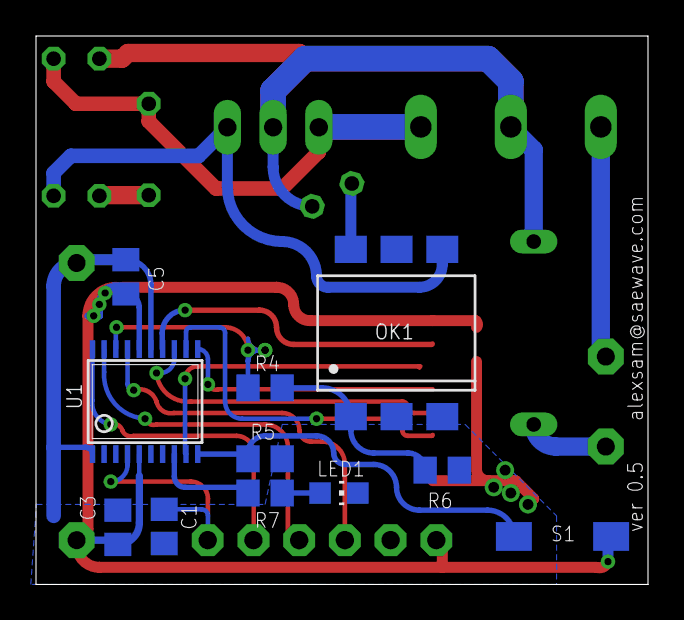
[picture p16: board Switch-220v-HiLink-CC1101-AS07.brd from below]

Board: 2 copper layers, 34.0 x 30.5 mm, 22 parts (11 on the bottom side), 23 nets.

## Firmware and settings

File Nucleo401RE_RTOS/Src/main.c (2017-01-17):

/**
  ******************************************************************************
  * File Name          : main.c
  * Description        : Main program body
  ******************************************************************************
  *
  * COPYRIGHT(c) 2016 STMicroelectronics
  *
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
  ******************************************************************************
  */
/* Includes ------------------------------------------------------------------*/
#include "adc.h"
#include "cmsis_os.h"
#include "crc.h"
#include "dma.h"
#include "gpio.h"
#include "iwdg.h"
#include "spi.h"
#include "stm32f4xx_hal.h"
#include "tim.h"
#include "usart.h"

/* USER CODE BEGIN Includes */
#include "nRF24L01P.h"
#include "timestamp.h"
#include "xdebug.h"
#include "rf_device.h"
/* USER CODE END Includes */


/* USER CODE BEGIN PV */
#define PUTCHAR_PROTOTYPE int fputc(int ch, FILE *f)
extern char *CompileTime;
extern char *CompileDate;
/* USER CODE END PV */

void SystemClock_Config(void);
void MX_FREERTOS_Init(void);

/* USER CODE BEGIN PFP */

/* USER CODE END PFP */

int main(void)
{

    /* MCU Configuration----------------------------------------------------------*/

    /* Reset of all peripherals, Initializes the Flash interface and the Systick. */
    HAL_Init();

    /* Configure the system clock */
    SystemClock_Config();

    /* Initialize all configured peripherals */
    MX_GPIO_Init();
    MX_DMA_Init();
    MX_ADC1_Init();
    MX_CRC_Init();
    MX_IWDG_Init();
    MX_SPI2_Init();
    MX_TIM10_Init();
    MX_USART2_UART_Init();
    MX_USART1_UART_Init();

    /* USER CODE BEGIN 2 */

    HAL_IWDG_Start(&hiwdg);

    /* Enable the UART Data Register not empty Interrupt */
    __HAL_UART_ENABLE_IT(&huart1, UART_IT_RXNE);
    __HAL_UART_ENABLE_IT(&huart1, UART_IT_IDLE);

    __HAL_UART_ENABLE_IT(&huart2, UART_IT_RXNE);
    __HAL_UART_ENABLE_IT(&huart2, UART_IT_IDLE);

    /*
  uint32_t g_ADCValue;
  HAL_ADC_Start(&hadc1);
  for(;;) {
    if (HAL_ADC_PollForConversion(&hadc1, 1000) == HAL_OK)
        {
          g_ADCValue = HAL_ADC_GetValue(&hadc1);
          dxprintf("ADC: %02x\n", (uint8_t)g_ADCValue);
          HAL_ADC_Start(&hadc1);
        }
  }
  */
    dxprintf("Compiled in: %s at %s!\n\n", CompileDate, CompileTime);

    nRF24_Configure();
    dxprintf("nRF24_Configure\n");
    nRF24_TXMode(&hspi2);
    //  dxprintf("nRF24_TXMode\n");
    nRF24_RXMode(&hspi2, 1);
    //  dxprintf("nRF24_RXMode\n");

    nRF24_HandleStatus(&hspi2, CHIP_Tx);
    dxprintf("nRF24_HandleStatus\n");

    dxprintf("All Ready!\n\n");

    //  HAL_TIM_Base_Start_IT(&htim10);
    //  HAL_TIM_Base_Start_IT(&htim11);
    
    rfLoadDevices();
    /* USER CODE END 2 */

    /* Call init function for freertos objects (in freertos.c) */
    MX_FREERTOS_Init();

    /* Start scheduler */
    osKernelStart();

    /* We should never get here as control is now taken by the scheduler */

    /* Infinite loop */
    /* USER CODE BEGIN WHILE */
    while (1)
    {
        /* USER CODE END WHILE */

        /* USER CODE BEGIN 3 */
    }
    /* USER CODE END 3 */
}

/** System Clock Configuration
*/
void SystemClock_Config(void)
{

    RCC_OscInitTypeDef RCC_OscInitStruct;
    RCC_ClkInitTypeDef RCC_ClkInitStruct;

    __HAL_RCC_PWR_CLK_ENABLE();

    __HAL_PWR_VOLTAGESCALING_CONFIG(PWR_REGULATOR_VOLTAGE_SCALE2);

    RCC_OscInitStruct.OscillatorType      = RCC_OSCILLATORTYPE_HSI | RCC_OSCILLATORTYPE_LSI;
    RCC_OscInitStruct.HSIState            = RCC_HSI_ON;
    RCC_OscInitStruct.HSICalibrationValue = 16;
    RCC_OscInitStruct.LSIState            = RCC_LSI_ON;
    RCC_OscInitStruct.PLL.PLLState        = RCC_PLL_ON;
    RCC_OscInitStruct.PLL.PLLSource       = RCC_PLLSOURCE_HSI;
    RCC_OscInitStruct.PLL.PLLM            = 16;
    RCC_OscInitStruct.PLL.PLLN            = 336;
    RCC_OscInitStruct.PLL.PLLP            = RCC_PLLP_DIV4;
    RCC_OscInitStruct.PLL.PLLQ            = 7;
    HAL_RCC_OscConfig(&RCC_OscInitStruct);

    RCC_ClkInitStruct.ClockType      = RCC_CLOCKTYPE_HCLK | RCC_CLOCKTYPE_SYSCLK | RCC_CLOCKTYPE_PCLK1 | RCC_CLOCKTYPE_PCLK2;
    RCC_ClkInitStruct.SYSCLKSource   = RCC_SYSCLKSOURCE_PLLCLK;
    RCC_ClkInitStruct.AHBCLKDivider  = RCC_SYSCLK_DIV1;
    RCC_ClkInitStruct.APB1CLKDivider = RCC_HCLK_DIV2;
    RCC_ClkInitStruct.APB2CLKDivider = RCC_HCLK_DIV1;
    HAL_RCC_ClockConfig(&RCC_ClkInitStruct, FLASH_LATENCY_2);

    HAL_SYSTICK_Config(HAL_RCC_GetHCLKFreq() / 1000);

    HAL_SYSTICK_CLKSourceConfig(SYSTICK_CLKSOURCE_HCLK);

    /* SysTick_IRQn interrupt configuration */
    HAL_NVIC_SetPriority(SysTick_IRQn, 15, 0);
}

/* USER CODE BEGIN 4 */

PUTCHAR_PROTOTYPE
{
    HAL_UART_Transmit(&huart2, (uint8_t *)&ch, 1, 0xFF);
    return ch;
}
/* USER CODE END 4 */

#ifdef USE_FULL_ASSERT

/**
   * @brief Reports the name of the source file and the source line number
   * where the assert_param error has occurred.
   * @param file: pointer to the source file name
   * @param line: assert_param error line source number
   * @retval None
   */
void assert_failed(uint8_t *file, uint32_t line)
{
    /* USER CODE BEGIN 6 */
    /* User can add his own implementation to report the file name and line number,*/
    dxprintf("Wrong parameters value: file %s on line %d\r\n", file, line);
    /* USER CODE END 6 */
}

#endif

/**
  * @}
  */

/**
  * @}
*/

/************************ (C) COPYRIGHT STMicroelectronics *****END OF FILE****/

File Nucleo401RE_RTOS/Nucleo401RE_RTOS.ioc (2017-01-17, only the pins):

Mcu.UserName=STM32F401RETx
PA0-WKUP.GPIO_Label=R_CE
PA0-WKUP.Signal=GPIO_Output
PA1.GPIO_Label=R_CSN
PA1.Signal=GPIO_Output
PA10.Signal=USART1_RX
PA2.GPIO_Label=USART_TX
PA2.Signal=USART2_TX
PA3.GPIO_Label=USART_RX
PA3.Signal=USART2_RX
PA4.GPIO_Label=R_IRQ
PA4.Signal=GPXTI4
PA5.GPIO_Label=LD2 [Green Led]
PA5.Signal=GPIO_Output
PA6.Signal=ADCx_IN6
PA9.Signal=USART1_TX
PB0.GPIO_Label=T_CSN
PB0.Signal=GPIO_Output
PB10.Signal=SPI2_SCK
PC0.GPIO_Label=T_CE
PC0.Signal=GPIO_Output
PC1.GPIO_Label=T_IRQ
PC1.Signal=GPXTI1
PC13-ANTI_TAMP.GPIO_Label=B1 [Blue PushButton]
PC13-ANTI_TAMP.Signal=GPXTI13
PC14-OSC32_IN.Signal=RCC_OSC32_IN
PC15-OSC32_OUT.Signal=RCC_OSC32_OUT
PC2.Signal=SPI2_MISO
PC3.Signal=SPI2_MOSI

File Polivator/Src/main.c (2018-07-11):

/* 
 * This file is part of the RemoteSwitch distribution 
 * (https://github.com/saewave/RemoteSwitch).
 * Copyright (c) 2018 Samoilov Alexey.
 * 
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
 * You should have received a copy of the GNU General Public License 
 * along with this program. If not, see <http://www.gnu.org/licenses/>.
 */

#include "F030C8_Peripheral.h"
#include "SI446x.h"
#include "config.h"
#include "core.h"
#include "rf_cmd.h"
#include "rf_cmd_exec.h"

#if MOVE_VECTOR_TABLE == 1
volatile uint32_t *VectorTable = (volatile uint32_t *)MAIN_PROGRAM_RAM_ADDRESS;
#endif

uint8_t Data[18];

typedef struct {
    uint8_t Seconds : 4;
    uint8_t TenSeconds : 4;

    uint8_t Minutes : 4;
    uint8_t TenMinutes : 4;

    uint8_t Hour : 4;
    uint8_t TenHour : 2;
    uint8_t TimeFormat : 2;

    uint8_t Day : 8;

    uint8_t Date : 4;
    uint8_t TenDate : 4;

    uint8_t Month : 4;
    uint8_t TenMonth : 3;
    uint8_t Century : 1;

    uint8_t Year : 4;
    uint8_t TenYear : 4;
} RTCDateTime;

typedef struct {
    uint8_t Seconds : 4;
    uint8_t TenSeconds : 3;
    uint8_t A1M1 : 1;

    uint8_t Minutes : 4;
    uint8_t TenMinutes : 3;
    uint8_t A1M2 : 1;

    uint8_t Hour : 4;
    uint8_t TenHour : 2;
    uint8_t TimeFormat : 1;
    uint8_t A1M3 : 1;

    uint8_t Date : 4;
    uint8_t TenDate : 2;
    uint8_t DayDate : 1;
    uint8_t A1M4 : 1;
} RTCAlarm1;

typedef struct {
    uint8_t Minutes : 4;
    uint8_t TenMinutes : 3;
    uint8_t A2M2 : 1;

    uint8_t Hour : 4;
    uint8_t TenHour : 2;
    uint8_t TimeFormat : 1;
    uint8_t A2M3 : 1;

    uint8_t Date : 4;
    uint8_t TenDate : 2;
    uint8_t DayDate : 1;
    uint8_t A2M4 : 1;
} RTCAlarm2;

RTCDateTime DateTime;
RTCAlarm1   Alarm1;
RTCAlarm2   Alarm2;
uint8_t     RegControl = 0x1D;
uint8_t     RegStatus  = 0x88;
uint8_t     RegCS[2];
uint8_t     tStatus[8]  = {0};
uint8_t     tBuf[10]    = {1, 2, 3, 4, 5, 6, 7, 8, 9, 0};
uint8_t     tParams[10] = {0};

int      HandleStatus = 1;
uint32_t Counter      = 0;
uint32_t Blink        = GPIO_BSRR_BR_10;

void InitPeriph(void)
{
    CRC_Configure();
    TIM_Configure();
    GPIO_Configure();
    USART_Configure();

    ADC_Configure();
    RTC_Configure();
    RTC_Time_Configure(0, 0, 0);
    RTC_Alarm_Configure(0xFF, 20, 0); //Alarm each 20 min (Check humidity)

    dxdev_out(USART_SendChar);
    SPI_Configure();
}

int main(void)
{
#if MOVE_VECTOR_TABLE == 1
    for (uint32_t i = 0; i < 48; i++) {
        VectorTable[i] = *(__IO uint32_t *)(MAIN_PROGRAM_START_ADDRESS + (i << 2));
    }
    SYSCFG->CFGR1 |= SYSCFG_CFGR1_MEM_MODE;
    RCC->APB2ENR |= RCC_APB2ENR_SYSCFGCOMPEN;
#endif
    __enable_irq();

    InitPeriph();

    if (SAE_READ_ADDR_ON_START) {
        readConfig();
    }

    Transceiver_Configure();

    dxputs("InitAll Done!\n\n");

#if SAE_ALL_TIME_RX_MODE == 1
    Transceiver_ClearFifo(Transceiver_CLEAR_TX_FIFO | Transceiver_CLEAR_RX_FIFO);
    Transceiver_RxMode();
    EXTI_Configure();
#endif

    rfStartup();

    TIM14->CR1 |= TIM_CR1_CEN;
//TIM16->CR1 |= TIM_CR1_CEN;
#if USE_STOP_MODE == 1
    GOTO_Stop();
    //We should never been here!
    dxputs("What I'm doing here?\n");
#endif
    while (1) {
#if USE_STOP_MODE == 0
        if (HandleStatus) {
            HandleStatus = 0x00;
            Transceiver_HandleStatus();
        }
#endif
    }
}

void uEXTI_IRQHandler(uint32_t Pin)
{
#if USE_STOP_MODE == 1
    Transceiver_HandleStatus();
#else
    HandleStatus = 1;
#endif
}

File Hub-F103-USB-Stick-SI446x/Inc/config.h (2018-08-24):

#ifndef __config_H
#define __config_H

#define SAE_CMD_BEGIN_CHAR1 0x41  // 'A'
#define SAE_CMD_BEGIN_CHAR2 0x54  // 'T'
#define SAE_CMD_BEGIN_CHAR3 0x2B  // '+'
#define SAE_CMD_BEGIN_HEXFW 0x3A  // ':'

#define SAE_CMD_LENGTH 50
#define SAE_CMD_QUEUE_LENGTH 5

#define SAE_DEVICE_LIST_LENGTH 10

#define SAE_ENABLE_USB 1

#define SAE_OUTPUT_DATA_LENGTH 100
#define SAE_OUTPUT_QUEUE_LENGTH 50

#define SAE_DEVICE_RX_QUEUE_LENGTH 5
#define SAE_DEVICE_TX_QUEUE_LENGTH 5

#define SAE_FW_UPDATE_LOCAL 0
#define SAE_FW_UPDATE_DEVICE 1

#define SAE_DEVICES_MEMORY_ADDRESS 0x08007C00       //last page of mem
#define SAE_START_MEMORY_ADDRESS 0x08000400         //start of programm address
#define SAE_FW_MEMORY_ADDRESS 0x08008000            //mid of mem
#define SAE_FW_SET_MEMORY_ADDRESS 0x0800FC00        //FW settings address (Length, CRC32, etc)
#define SAE_END_MEMORY_ADDRESS 0x08010000           //End mem
#define SAE_BOOT_MEMORY_ADDRESS 0x08000000          //bootloader start addr
#define SAE_BOOT_Size 0x400                         //bootloader size ( 1024B )
#define SAE_CPU_FREQUENCY 72000000

//#define SAE_ENABLE_DEBUG

#endif /* __config_H */

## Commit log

2016-04-22 Add Switch-220v-8Ch
2016-05-18 New Switch-1Ware-4Ch-p
2016-05-20 Fix some errors in Device when send package to Hub
    [Nucleo401RE_RTOS.ioc, main.c, nRF24L01P.c]
2016-12-13 Code refactor and new template for STM32F030F4
2016-12-16 Add Bootloader template Switch-Template, some refactoring
2016-12-16 Use low power template for 1Wire thermometer
2017-01-17 Add RPi HUB STM32F103
2017-01-17 Add PowerOff to save power consumption
2017-01-17 Fix wrong pin
2017-01-17 Add PowerOff to DeviceLib
2017-01-17 Add files for HUB STM32F103
2017-05-05 Add Eagle Schematic and Boards for USB Hub, 220 AC switch and AA bat remote device
    [Hub USB 2.0.brd, Hub USB 2.0.sch, Switch-0.8-5.5v-ds18b20-1-4Ch.brd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]
2017-05-05 Eagle library for Devices and Hub
2017-05-11 Add 4Ch 12V controller
    [Switch-12v-PWM-4Ch.brd, Switch-12v-PWM-4Ch.sch]
2017-05-11 Update Switch-12v-PWM-4Ch
    [Switch-12v-PWM-4Ch.brd, Switch-12v-PWM-4Ch.sch]
2017-05-11 Update Switch-12v-PWM-4Ch - replace driver to IR4427S
    [Switch-12v-PWM-4Ch.brd, Switch-12v-PWM-4Ch.sch]
2017-05-27 Add new device Switch-1Ware-4Ch-CC1101-F030F4
2017-05-27 Add Eagle boad and schematic for device Switch-1Ware-4Ch-CC1101-F030F4
    [Switch-0.8-5.5v-ds18b20-1-4Ch.brd, Switch-0.8-5.5v-ds18b20-1-4Ch.sch]
2017-08-20 Update schematic and boards
    [Hub USB 2.0.brd, Hub USB 2.0.sch, Switch-0.8-5.5v-ds18b20-1-4Ch.brd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]
2017-12-17 Add Switch-Template-CC1101-F030
2017-12-17 Remove Switch-1Ware-4Ch-CC1101-F030F4
2017-12-17 Remove Switch-Template, Switch-1Ware-4Ch-p, 'Switch-1Ware-4Ch as legacy code
2017-12-17 Add Switch-4Ch-CC1101-F030F4 as main device for new board
2017-12-17 Update FWUpdater and add code for emulate devices
2017-12-24 Update Switch-4Ch-CC1101-F030F4
2018-02-18 Fix minor bugs in Hub-F103-USB-Stick-CC1101
    [CC1101.c, F103RE_Peripheral.c, core.h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]
2018-02-18 Change output power to 10dB for transmitter
2018-05-27 Update Hub USB 2.0 schematic
    [Hub USB 2.0.brd, Hub USB 2.0.sch]
2018-05-27 Update Switch-12v-PWM-4Ch schematic
    [Switch-12v-PWM-4Ch.brd, Switch-12v-PWM-4Ch.sch]
2018-05-27 Add Bootloader for STM32F103 to update firmware
2018-07-11 Add Polivator to SchematicAndBoards
    [Polivator.brd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]
2018-08-24 Update Hub USB 2.0, add achematic in PDF
    [Hub USB 2.0.brd, Hub USB 2.0.sch]
2018-08-24 Update Hub USB 2.0.sch
    [Hub USB 2.0.sch]

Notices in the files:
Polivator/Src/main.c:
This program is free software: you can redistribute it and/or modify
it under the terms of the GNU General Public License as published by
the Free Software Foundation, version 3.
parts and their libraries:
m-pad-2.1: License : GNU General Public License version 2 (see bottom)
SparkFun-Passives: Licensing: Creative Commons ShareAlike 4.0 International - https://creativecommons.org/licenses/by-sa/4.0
